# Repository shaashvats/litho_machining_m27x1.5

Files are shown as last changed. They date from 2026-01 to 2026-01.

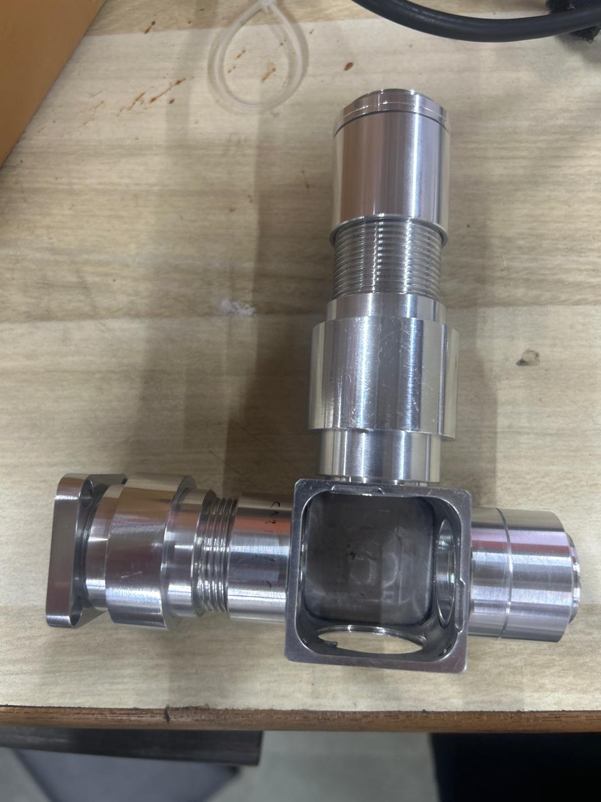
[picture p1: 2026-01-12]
img2.jpeg

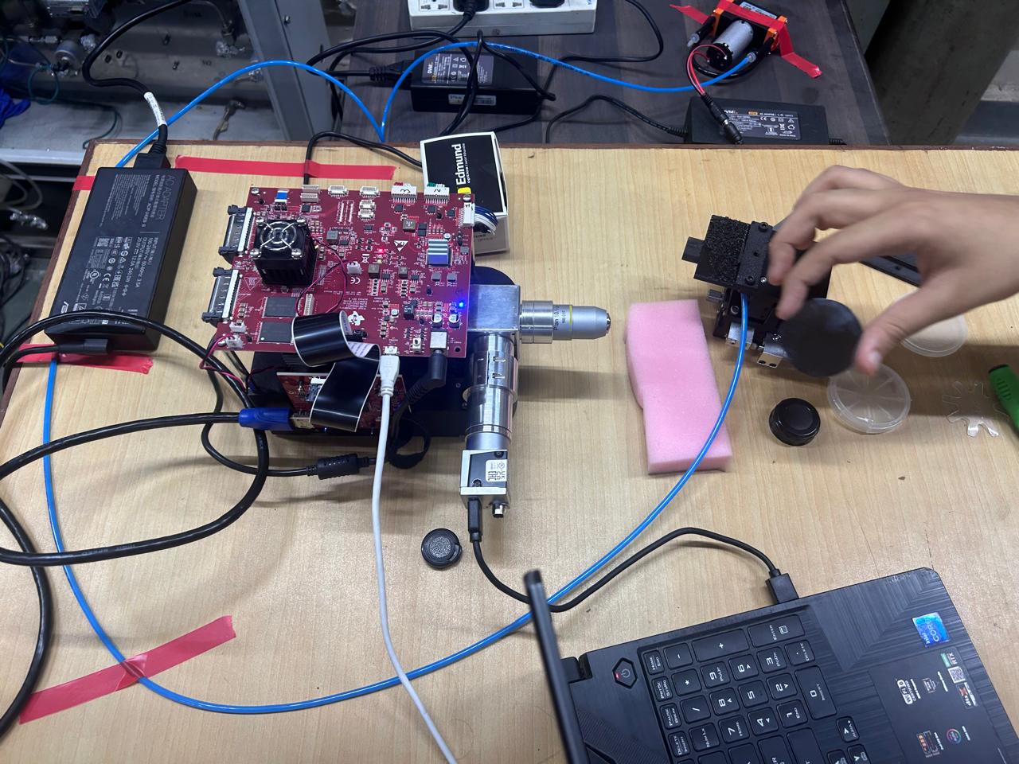
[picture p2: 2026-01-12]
img3.jpeg

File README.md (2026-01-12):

# litho_machining_m27x1.5

Full Build instructions https://docs.hackerfab.org/home/fab-toolkit/patterning/lithography-stepper-v2-build-work-in-progress

Changes from The Thor Labs Components:

This is V1 of trying to machine our own Thorlabs parts. They are compatible with each other, but not with the Thor Labs parts. In V2, we will attempt to make duplicates of the Thorlabs components at a lower cost.

Build this only if on a budget, or without access to a *great machining facility*. Buy the Thorlabs setup if you can. 

Thor labs using SM1 threading for the optics. Our local machine shop couldn't make threading that fine, so we adapted the parts to M27x1.5 which has a larger pitch, while keeping a similar optical axis diameter. The threading for mounts to the Camera, and lens remain the same

When we gave our parts for machining, we used an inner dia of 25 mm for M27x1.5 which damaged the thread tapping tool. For the drawings we are sharing, the inner dia to do before female threading has been updated to 25.5 mm.

The step files and drawings can be shared directly with a machine shop, and can be used as it is.

All parts except the cube, and the friction couplers can be made on a lathe. Our machine shop made the threads for the CM1 replacement on the VMC machine, since taps for this are not readily available.

This was made as a quick prototype. Some chamfering of edges etc is missing and can be added if needed for machining.

The length setter (5b, 9b) for the Variable couplers (SM1V05, SM1V10) have been made thicker because our threading pitch is larger than that of the Thor Labs parts

Further Procurement
- 4x Adapter Plate - M2 countersunk 10mm 
- 4x SM1A53 (sq plate) M3 5mm round head 
- 4x Friction couplers M2 (< 3.81 mm head) 10mm screw 
- 2x CM1 (box) M2.5 Flat head screws 4mm flat head
- 2x CM1 (box) M3 8mm FLat bottom of screw head  (5.9mm OD for screw head)
- 2x CM1 Dowel < 1.5875 mm Dia (We bought a 1.5 mm drill head and broke it)
- 2x CM1 Spring (Misumi India) (1.5875 mm < spring <2.413 mm dia) (Length = 10mm nominal )

Threading instructions

- m27 x 1.5

- 25.5 inner dia on female threading
- 26.9 mm outer dia on male threading

Duplicates:
- 7, 10 = SM1L10
- 3, 13 = SM1L03
- 6, 12 = SM1L05

Assembly

DLP
- 2 screws into 1 (4x m screws)
- 3 screws 2 (main hole)
- 4 joins 3 and 5 (by friction from outside)
- 5 screws into 6 (main hole)
- 6 screws into 15 (main hole)

Camera 
- 9 screws into 10 (main hole)
- 10 screws into 11 (main hole)
- 11 screws into camera (main hole)
- 8 joins 7 and 9 (by friction from outside)
- 7 screws into 15 (main hole)

Microscope (microscope -> 14 -> 12 -> 13 -> 15)
- 13 screws into 15
- 12 screws into 13
- 14 screws into 12
- microscope screws into 14

Assembly (we are replicating)
https://cad.onshape.com/documents/64016e74334e9df7f3829a37/w/da5b11336b83f611c84f6d9f/e/345550da08271685cbf13c97

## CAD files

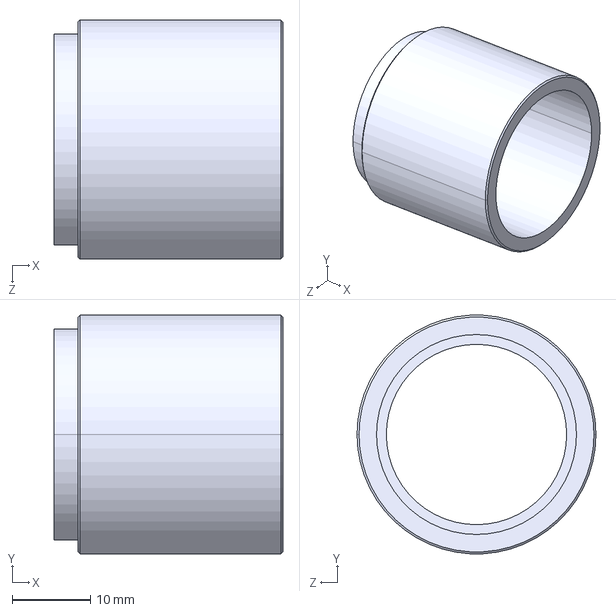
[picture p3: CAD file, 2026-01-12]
10_SM1L10 - Copy/SM1L10-Solidworks.STEP
29.2 x 30.4 x 30.5 mm

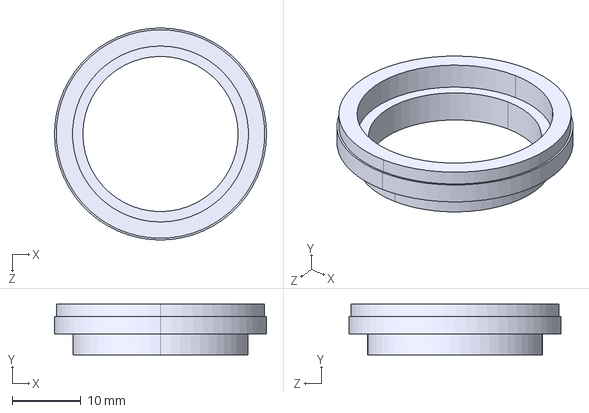
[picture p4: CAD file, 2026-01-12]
11_SM1A9/SM1A9_redesign.STEP
30.7 x 7.37 x 30.7 mm

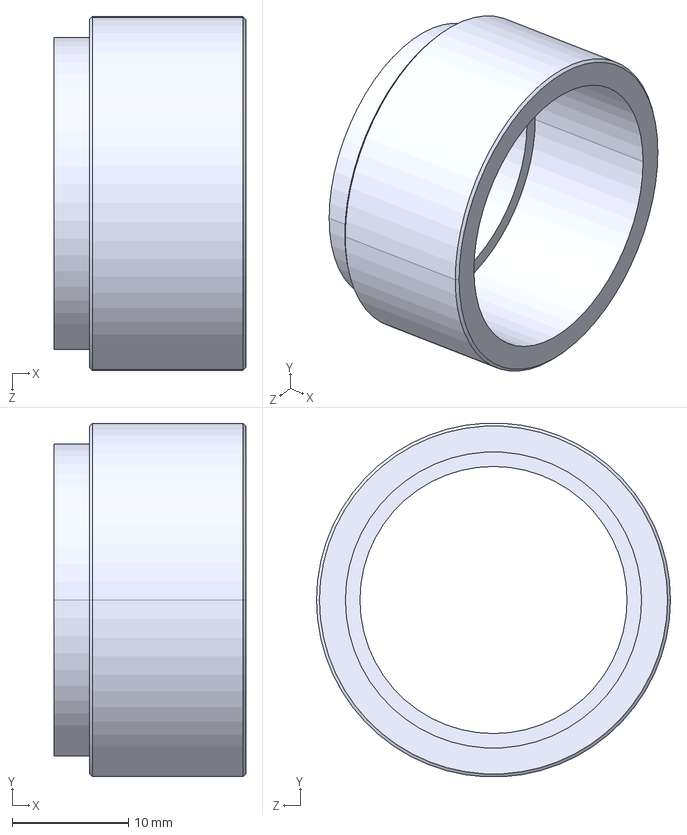
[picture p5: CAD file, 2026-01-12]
12_SM1L05_tube - Copy/6_SM1L05_tube/SM1L05-Solidworks.STEP
16.5 x 30.4 x 30.5 mm

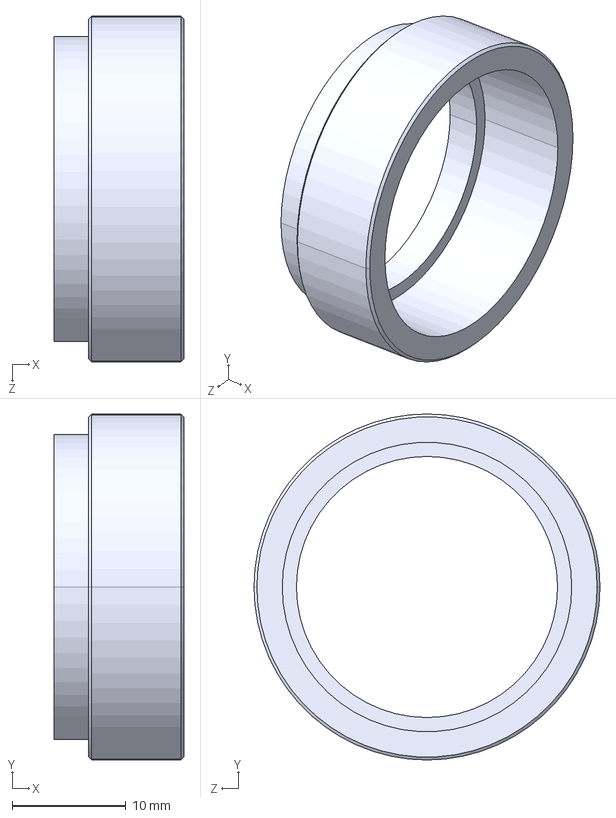
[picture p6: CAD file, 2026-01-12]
13_SM1L03_Thrlength - Copy/SM1L03-Solidworks.STEP
11.4 x 30.5 x 30.5 mm

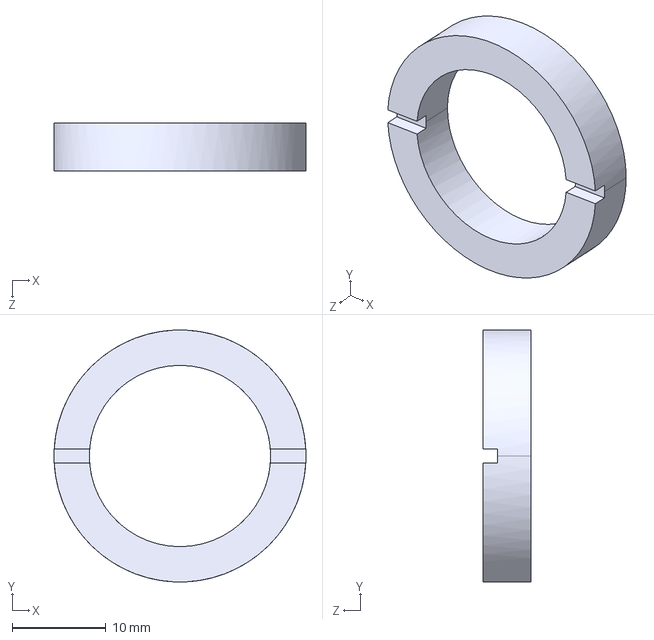
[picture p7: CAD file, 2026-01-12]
14_SM1A3_converter/SM1A3-Solidworks.STEP
26.9 x 26.9 x 5.08 mm

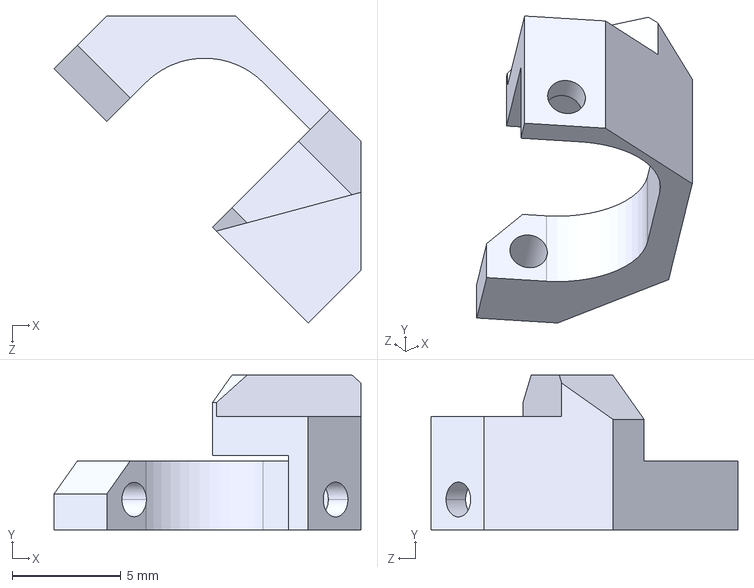
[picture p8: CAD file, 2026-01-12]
15_CM1_DCH/CM1-DCH-clamp2.STEP
14.1 x 7.11 x 14.1 mm

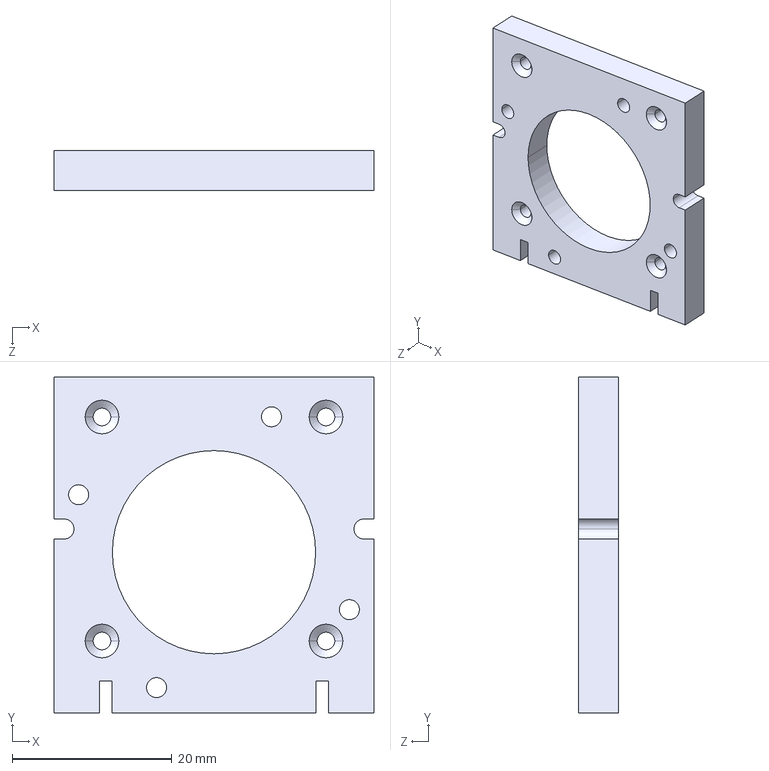
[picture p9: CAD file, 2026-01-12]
1_adapter/adapter plate - Part 1.STEP
40.0 x 42.0 x 5.00 mm

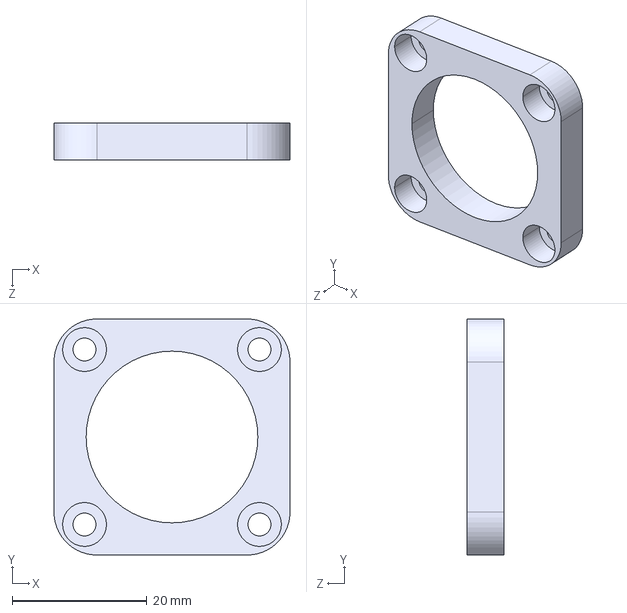
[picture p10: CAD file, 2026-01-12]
2_SM1A53_Sqpl/SM1A53-Solidworks.STEP
35.1 x 35.1 x 5.56 mm

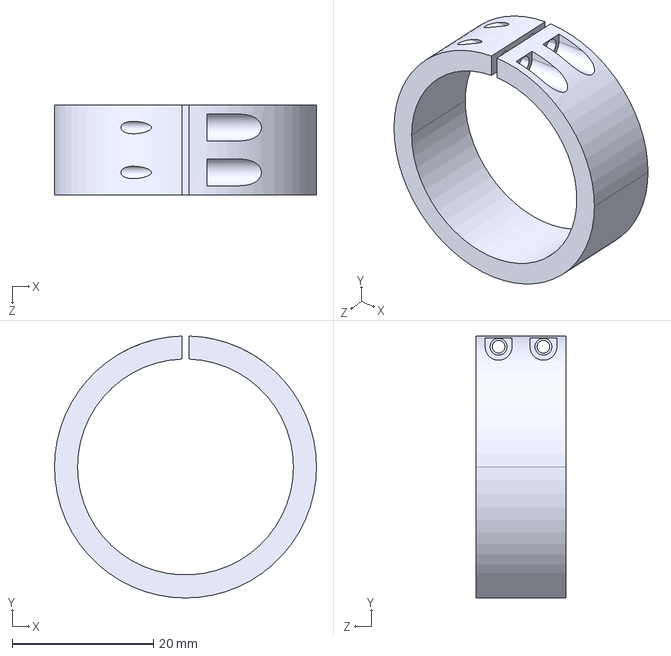
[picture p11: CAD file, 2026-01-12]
4_SM1CPL05_FrictionCoupler/SM1CPL05-Solidworks.STEP
37.1 x 37.1 x 12.7 mm

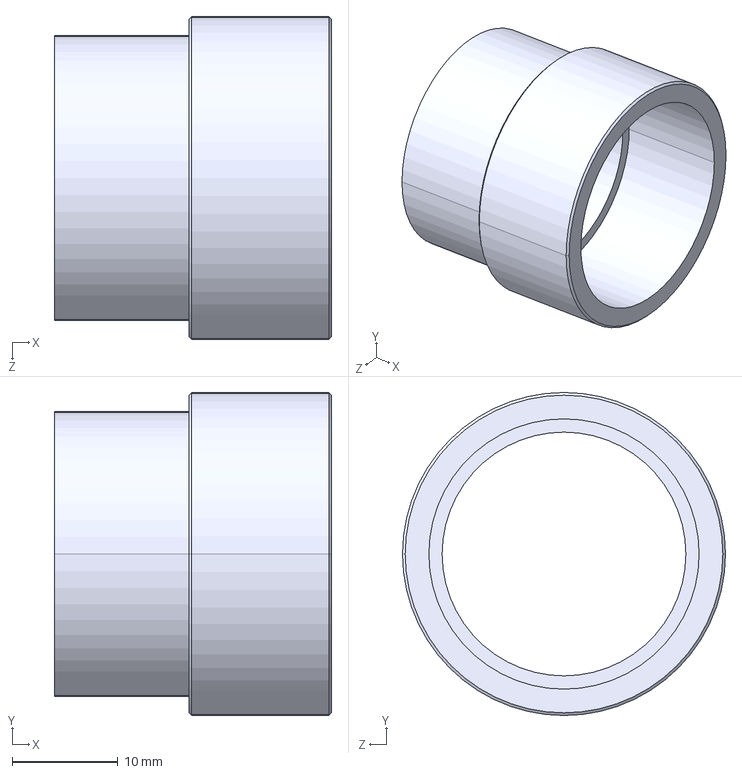
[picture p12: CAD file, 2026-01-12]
5a_SM1V05_adjustableTube/SM1V05-Solidworks.STEP
26.2 x 30.5 x 30.5 mm

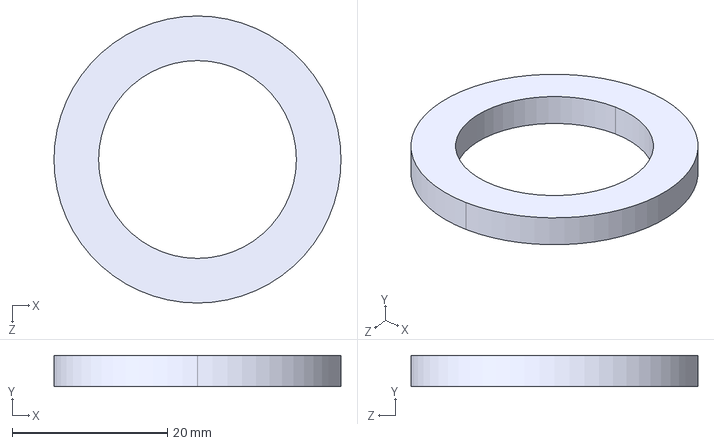
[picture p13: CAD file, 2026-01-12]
5b_var/16_2x_variable_friction_holder.STEP
37.0 x 4.00 x 37.0 mm

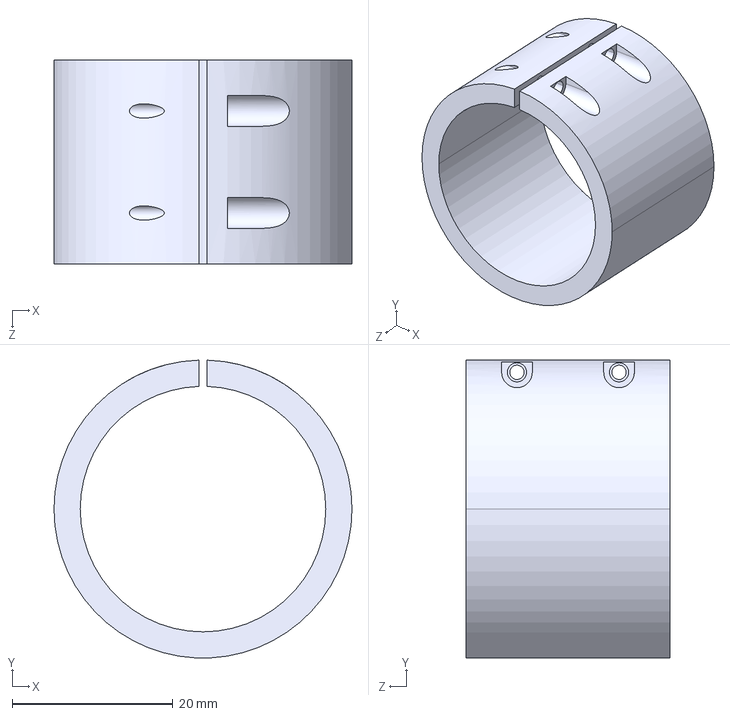
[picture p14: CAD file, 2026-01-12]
8_SM1CPl10/SM1CPL10-Solidworks.STEP
37.1 x 37.0 x 25.4 mm

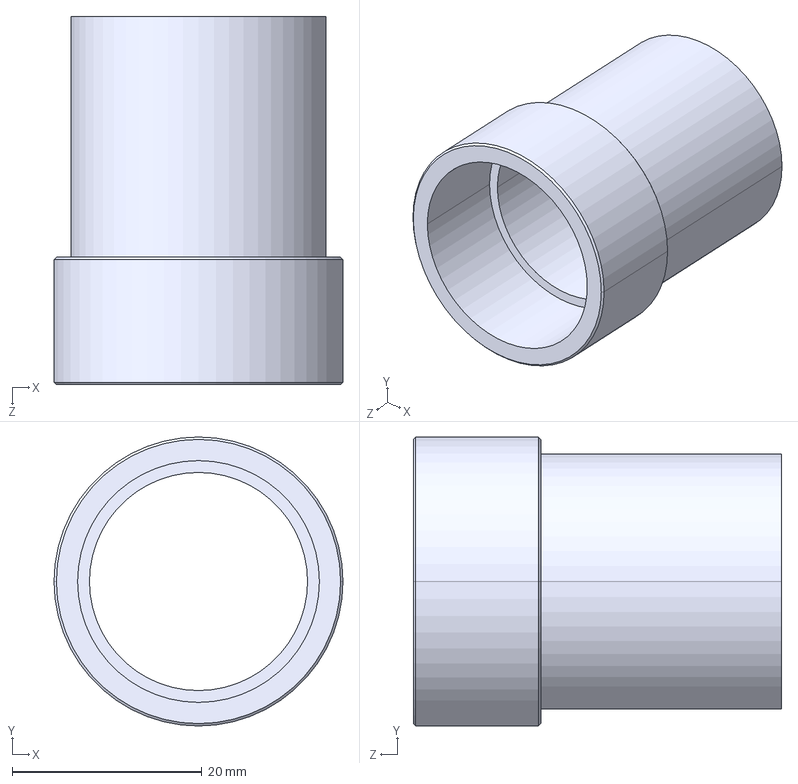
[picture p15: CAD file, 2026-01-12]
9a_SM1V10/SM1V10-Solidworks.STEP
30.5 x 30.5 x 38.9 mm

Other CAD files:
10_SM1L10 - Copy/SM1L10-Solidworks.SLDDRW
10_SM1L10 - Copy/SM1L10-Solidworks.sldprt
11_SM1A9/SM1A9_redesign.SLDDRW
11_SM1A9/SM1A9_redesign.SLDPRT
12_SM1L05_tube - Copy/6_SM1L05_tube/SM1L05-Solidworks.SLDDRW
12_SM1L05_tube - Copy/6_SM1L05_tube/SM1L05-Solidworks.sldprt
12_SM1L05_tube - Copy/SM1L05-Solidworks.SLDDRW
12_SM1L05_tube - Copy/SM1L05-Solidworks.sldprt
13_SM1L03_Thrlength - Copy/SM1L03-Solidworks.SLDDRW
13_SM1L03_Thrlength - Copy/SM1L03-Solidworks.sldprt
14_SM1A3_converter/SM1A3-Solidworks.SLDDRW
14_SM1A3_converter/SM1A3-Solidworks.sldprt
15_CM1_DCH/CM1-DCH-Solidworks.SLDDRW
15_CM1_DCH/CM1-DCH-Solidworks.sldprt
15_CM1_DCH/CM1-DCH-bottom.STEP
15_CM1_DCH/CM1-DCH-clamp1.STEP
15_CM1_DCH/CM1-DCH-splitterbase.STEP
15_CM1_DCH/CM1-DCH-top.STEP
1_adapter/adapter plate - Part 1.SLDDRW
1_adapter/adapter plate - Part 1.sldprt
2_SM1A53_Sqpl/SM1A53-Solidworks.SLDDRW
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

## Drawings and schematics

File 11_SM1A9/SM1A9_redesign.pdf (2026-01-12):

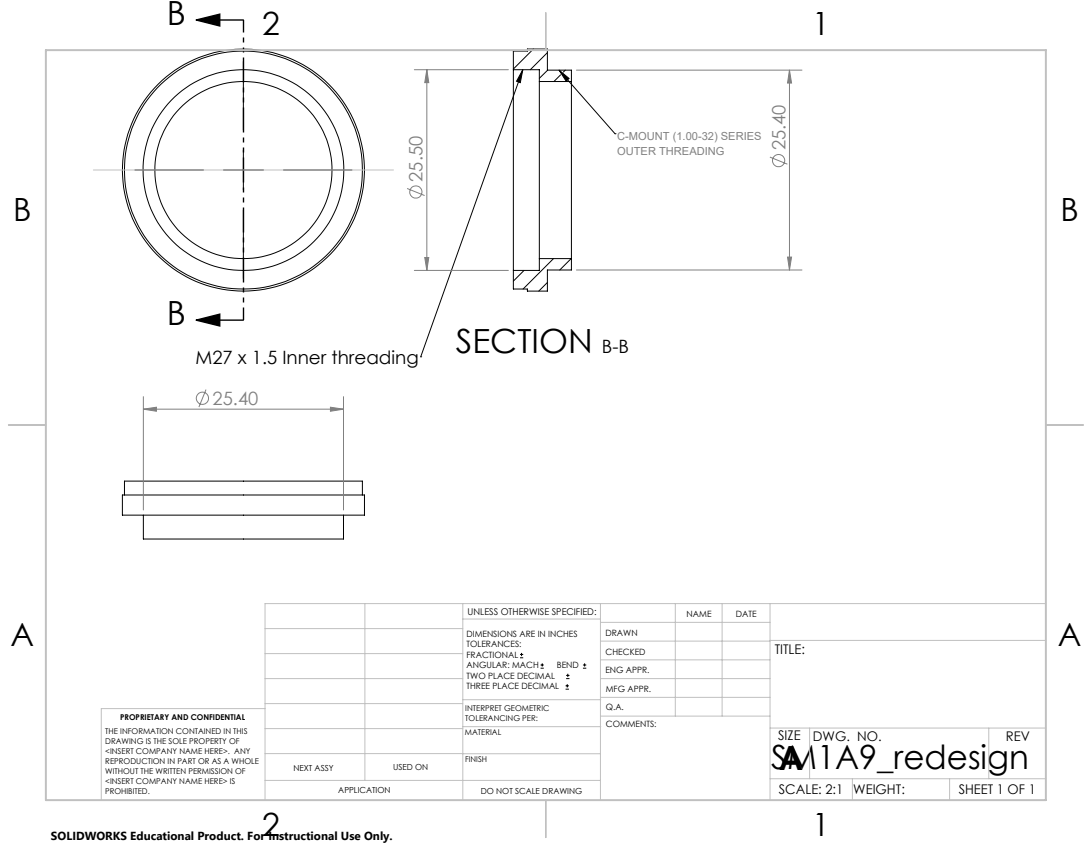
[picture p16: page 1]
SECTION B-B; C-MOUNT (1.00-32) SERIES OUTER THREADING; M27 x 1.5 Inner threading

UNLESS OTHERWISE SPECIFIED: | | NAME | DATE
DIMENSIONS ARE IN INCHES TOLERANCES: FRACTIONAL ANGULAR: MACH BEND TWO PLACE DECIMAL THREE PLACE DECIMAL | DRAWN

CHECKED | | | TITLE:

ENG APPR.
MFG APPR.

INTERPRET GEOMETRIC TOLERANCING PER: | Q.A.
MATERIAL | | SIZE SM1A9_redesign A | DWG. NO. | REV

PROPRIETARY AND CONFIDENTIAL
THE INFORMATION CONTAINED IN THIS
DRAWING IS THE SOLE PROPERTY OF
<INSERT COMPANY NAME HERE>. ANY
REPRODUCTION IN PART OR AS A WHOLE
WITHOUT THE WRITTEN PERMISSION OF
<INSERT COMPANY NAME HERE> IS
PROHIBITED.

NEXT ASSY | USED ON | FINISH

APPLICATION | DO NOT SCALE DRAWING | | SCALE: 2:1 | WEIGHT: | SHEET 1 OF 1

SOLIDWORKS Educational Product. For Instructional Use Only.

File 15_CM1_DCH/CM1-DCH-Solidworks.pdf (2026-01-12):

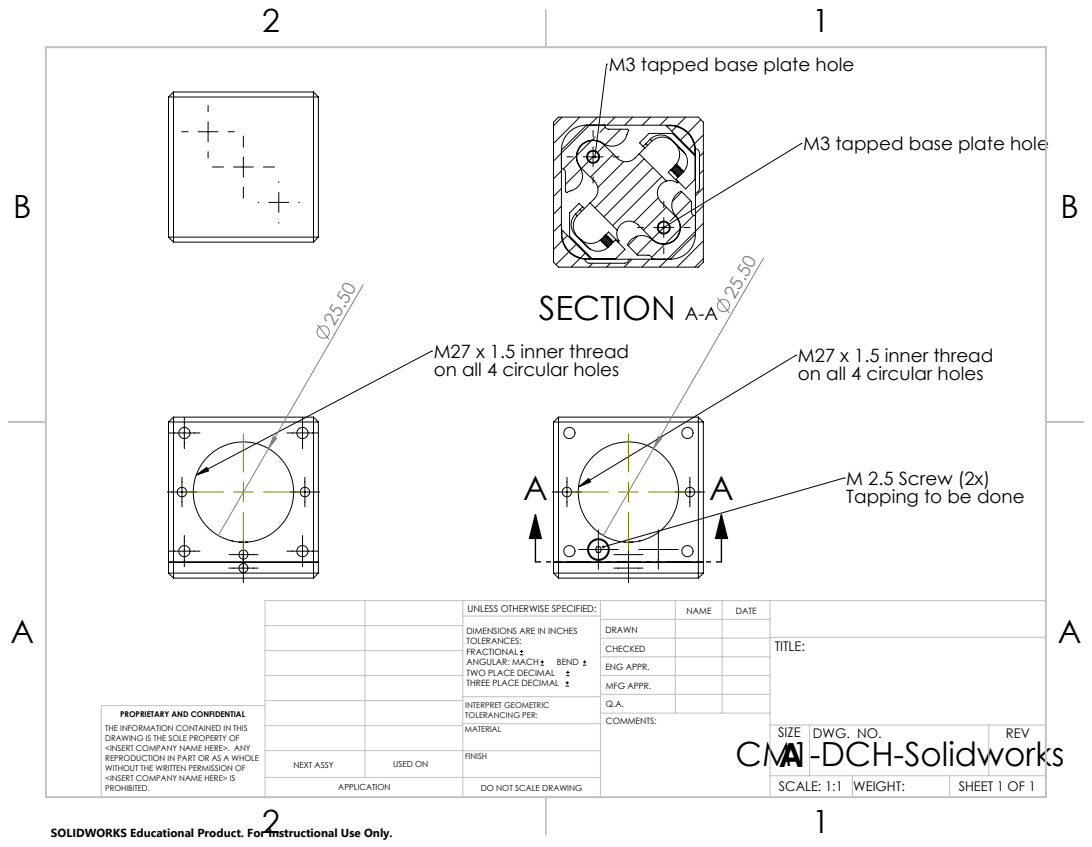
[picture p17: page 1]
SECTION A-A

M3 tapped base plate hole

M27 x 1.5 inner thread
on all 4 circular holes

M 2.5 Screw (2x)
Tapping to be done

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

CHECKED | | | TITLE:

ENG APPR.
MFG APPR.

INTERPRET GEOMETRIC TOLERANCING PER: | Q.A.
MATERIAL | | SIZE A | DWG. NO. | REV

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

NEXT ASSY | USED ON | FINISH

APPLICATION | DO NOT SCALE DRAWING | | SCALE: 1:1 | WEIGHT: | SHEET 1 OF 1

SOLIDWORKS Educational Product. For Instructional Use Only.

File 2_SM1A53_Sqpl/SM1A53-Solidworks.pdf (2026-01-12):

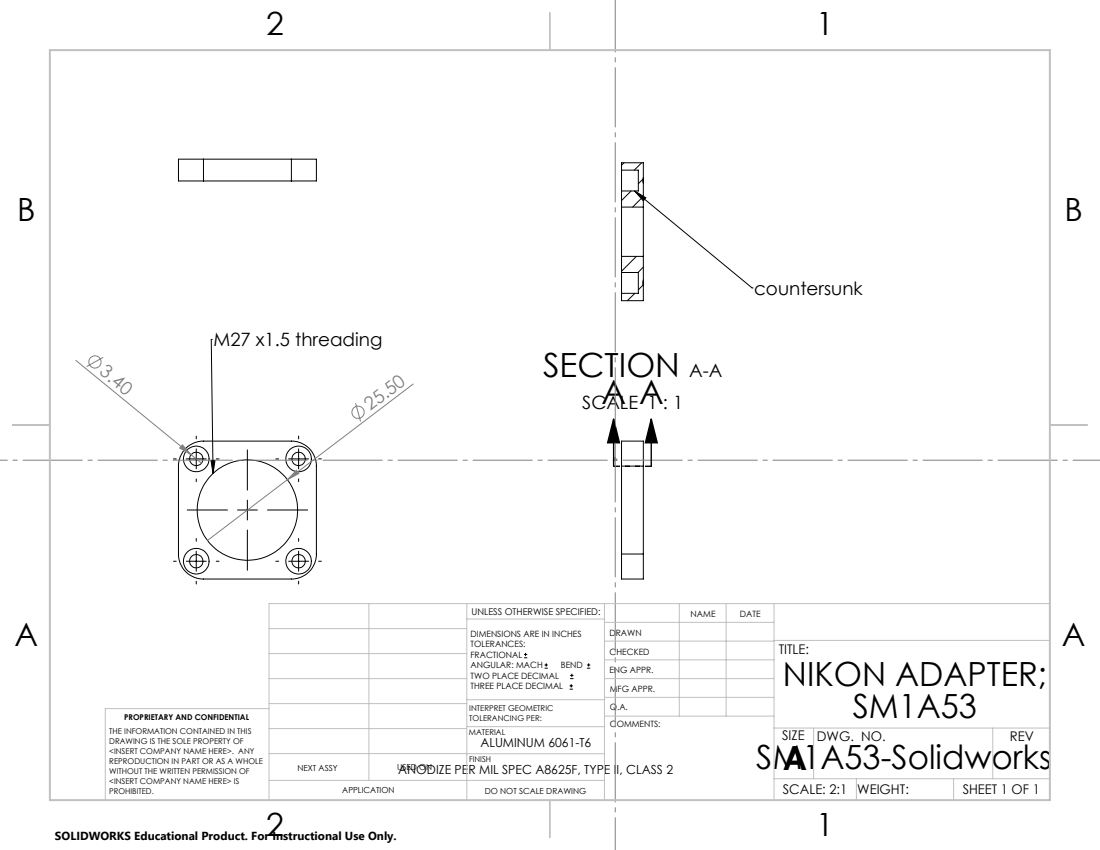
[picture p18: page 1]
M27 x1.5 threading; SECTION A-A; SCALE 1 : 1

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

CHECKED | | | TITLE: NIKON ADAPTER; SM1A53

ENG APPR.
MFG APPR.

INTERPRET GEOMETRIC TOLERANCING PER: | Q.A.
MATERIAL ALUMINUM 6061-T6 | | SM1A53-Solidworks | SIZE A | DWG. NO. | REV

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

COMMENTS:

NEXT ASSY | ANODIZE PER MIL SPEC A8625F, TYPE II, CLASS 2 FINISH USED ON

APPLICATION | DO NOT SCALE DRAWING | | | SCALE: 2:1 | WEIGHT: | SHEET 1 OF 1

SOLIDWORKS Educational Product. For Instructional Use Only.
